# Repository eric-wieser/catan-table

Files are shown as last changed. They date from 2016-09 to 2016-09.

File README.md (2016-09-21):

# catan-table
[OpenSCAD](http://www.openscad.org/) files for a [Settlers of Catan](http://www.catan.com/) table.

(http://imgur.com/xAjEHfm)

This comes in two parts:
* a volume to be removed from the center of a table ([stl](https://github.com/eric-wieser/catan-table/blob/master/table.stl))
* a piece to be made out of 0.25in plexiglass. ([stl](https://github.com/eric-wieser/catan-table/blob/master/plexiglass.stl))

## Manufacturing instructions

`table-combined.dxf` contains all the outlines to be cut into the table, which were cut as follows:

1. Outer hexagon: Cut with a 1" bit to a depth of 1/4"
2. Pentagons (boats): Cut with a 0.25" bit to a depth of 5/16"
3. Inner bounding polygon and contained rectangles: Cut with a 0.25" bit to a depth of 3/8"
4. Pentagons and bounding polygon: Finished with a 1/16" bit, to the same depths as before

## [Photos](https://imgur.com/a/w7VND)

Cut table complete with pieces (http://imgur.com/WMLwQrA)

Close up (http://imgur.com/FrY5nsx)

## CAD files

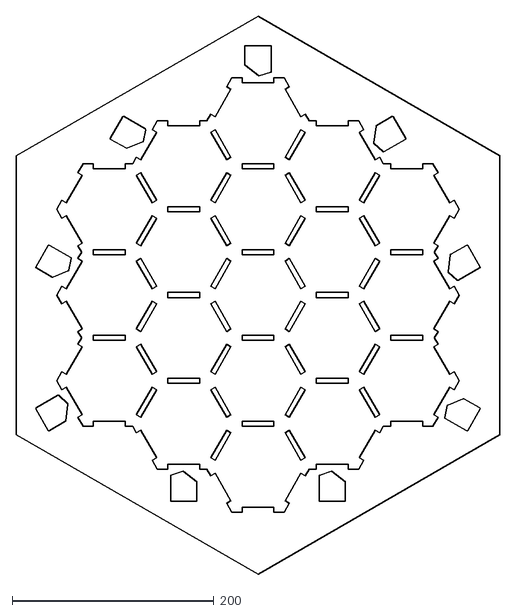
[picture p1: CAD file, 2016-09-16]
table-combined.dxf
478.9 x 553.0

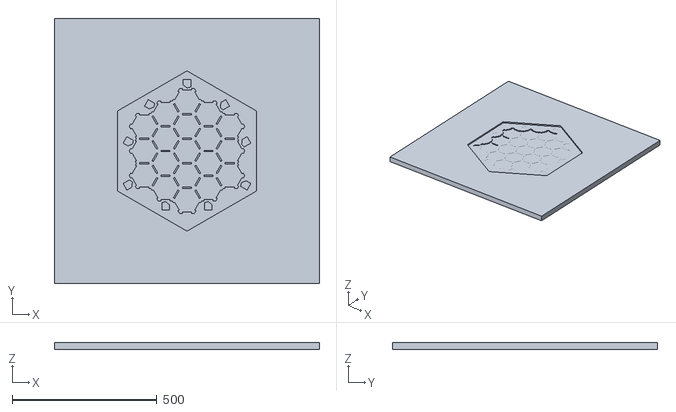
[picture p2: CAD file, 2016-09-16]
table.stl
914.4 x 914.4 x 25.4

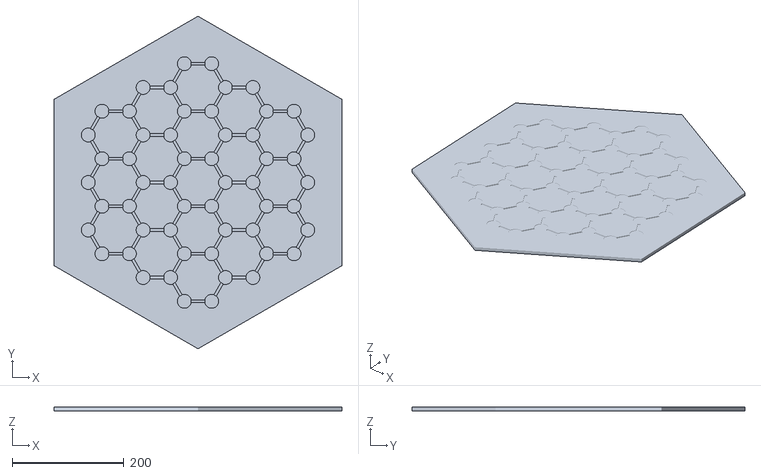
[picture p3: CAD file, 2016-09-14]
plexiglass.stl
515.8 x 595.6 x 6.35

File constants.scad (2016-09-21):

include <units.scad>;

plexiglass_thickness = 0.25*in;
tile_padding = 0.2*in;
spacing = 80*mm + tile_padding;
card_thickness = 1/16*in;

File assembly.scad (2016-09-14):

use <plexiglass.scad>
use <table.scad>

plexiglass();
cut_table();

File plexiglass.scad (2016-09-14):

include <units.scad>;
include <constants.scad>;
include <util.scad>;

module plexiglass() {
    color([1, 1, 1, 0.5])
        difference() {
            scale([1, 1, -1]) rotate([0, 0, 30])
                cylinder($fn=6, r=3.5*spacing, h=plexiglass_thickness);

            for_line2d(edge_pairs) {
                road();
            }
            
            scale([1, 1, -1]) for_point2d(corners) {
                cylinder(r=12.5*mm, h=2*mm, center=true);
            }
        }
}

plexiglass();

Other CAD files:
table.scad
units.scad
util.scad

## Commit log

2016-09-14 All of the things
    [assembly.scad, constants.scad, plexiglass.scad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]
2016-09-15 Tidy edge pairs
    [util.scad]
2016-09-15 Add boat cut-outs
    [table.scad, table.stl, units.scad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]
2016-09-16 Add final dxfs
    [constants.scad, table-combined.dxf, table.scad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]
2016-09-21 Create model by default
    [table.scad]
2016-09-21 Missed semicolon
    [util.scad]
2016-09-21 Update thickness to match that of the manufactured one
    [constants.scad]
